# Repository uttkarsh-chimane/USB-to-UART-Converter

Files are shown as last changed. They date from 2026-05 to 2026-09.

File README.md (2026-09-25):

<h1 align="center">💡 USB Type-C to UART Converter</h1>

<p align="center">
  
  
  
  
  
</p>

---

## ⚙️ What I Built

A compact, production-style USB-to-UART bridge designed in KiCad using the CP2102N USB-to-serial interface IC.

The board enables reliable serial communication between a host PC and embedded systems for debugging, firmware flashing, and data exchange. It is designed as a plug-and-play development tool that replaces generic USB-to-UART adapters with a cleaner, integrated hardware solution.

--- 

## 🚀 Overview

This project implements a robust USB-to-UART hardware interface using a USB Type-C connector and the CP2102N USB bridge IC.

---

## 📷 Project Gallery

🧩 **3D PCB Render**

Final assembled board visualization from KiCad 3D viewer.

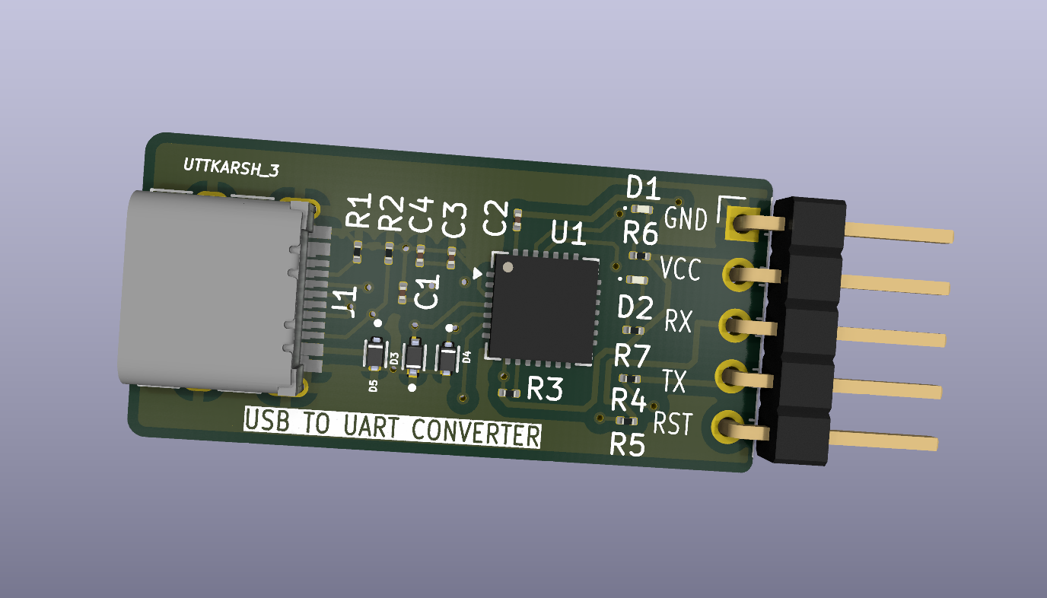
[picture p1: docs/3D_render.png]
3D PCB


🟠 **PCB Layout – Top Copper**

Top layer routing showing USB interface, CP2102N placement, and signal routing.

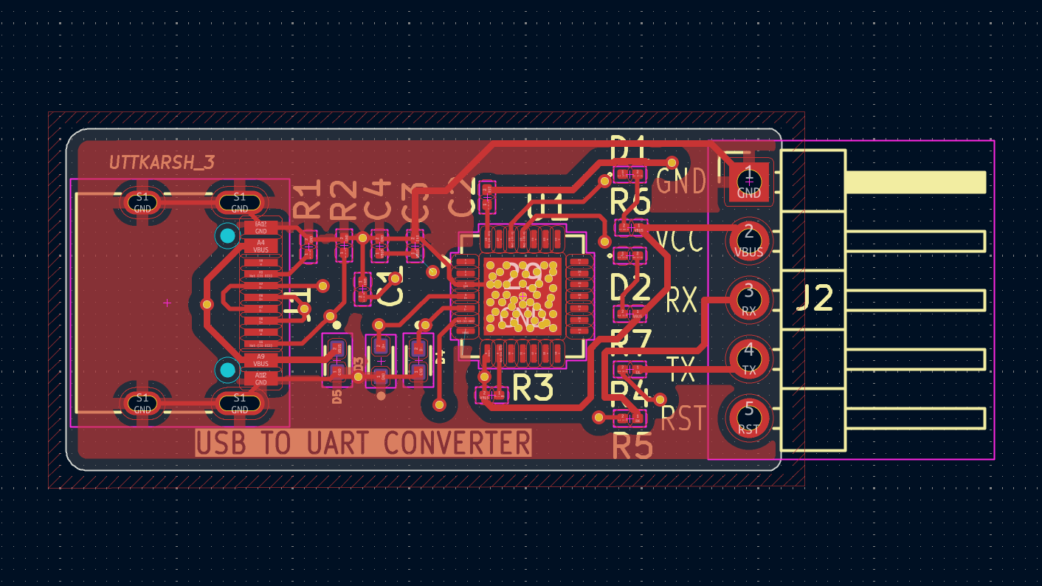
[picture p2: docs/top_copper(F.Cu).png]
Top Copper


🔵 **PCB Layout – Bottom Copper**

Bottom layer used for ground plane and signal return integrity.

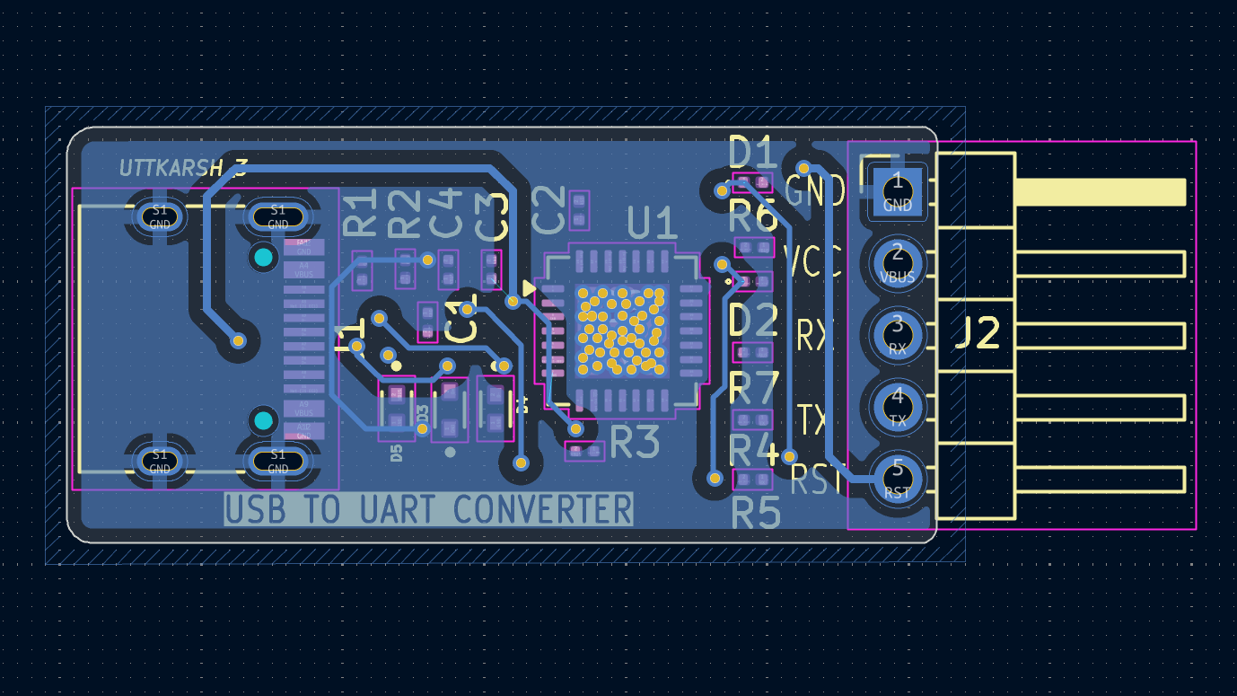
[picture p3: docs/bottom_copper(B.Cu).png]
Bottom Copper


⚙️ **Schematic – Power Section**

Power input stage including USB VBUS handling, decoupling, and regulation strategy.

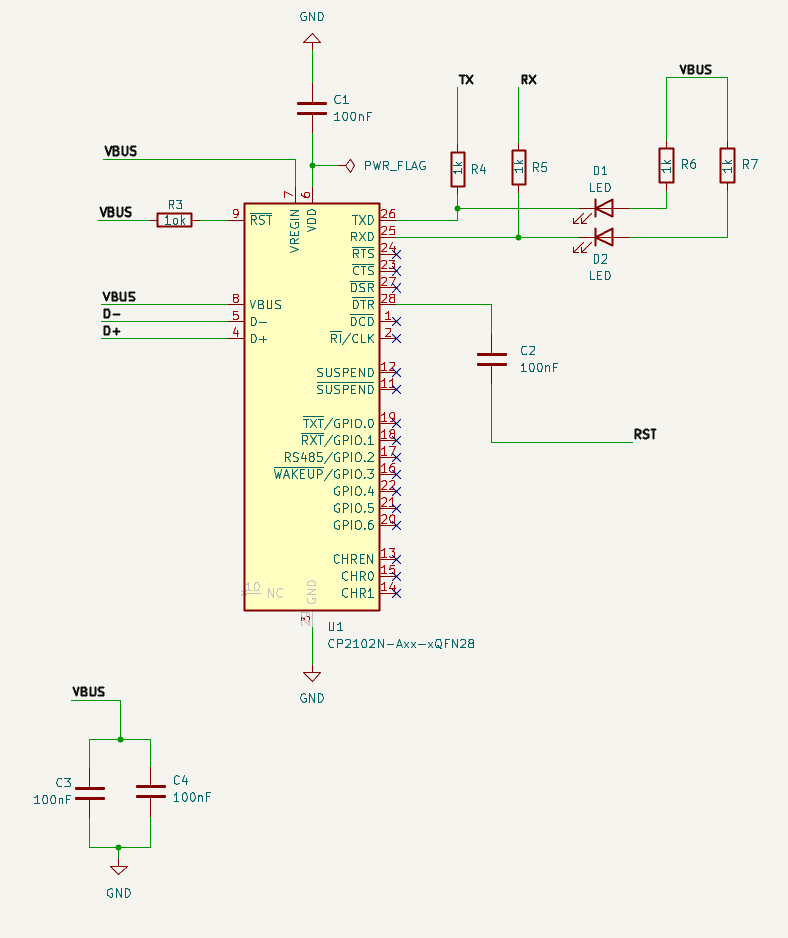
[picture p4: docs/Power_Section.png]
Power Schematic


🔌 **Schematic – USB Interface Section**

USB Type-C interface with CC resistors, ESD protection, and data routing.

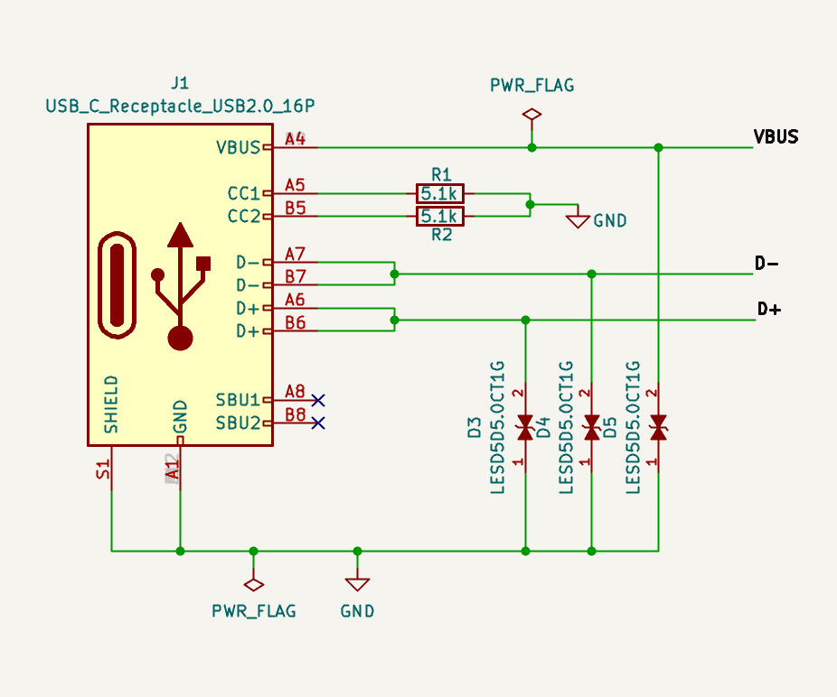
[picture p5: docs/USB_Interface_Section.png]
USB Schematic


📡 **Schematic – UART Interface Section**

CP2102N UART communication block with TX/RX routing and headers.

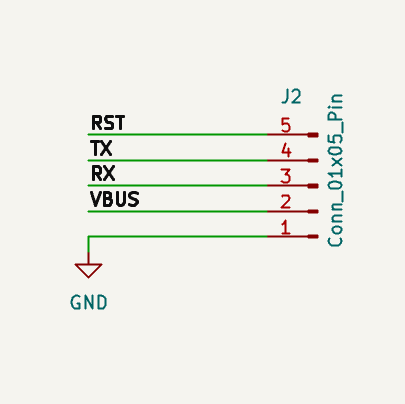
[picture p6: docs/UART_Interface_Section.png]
UART Schematic


---

## ✨ Features

* USB Type-C interface (USB 2.0)
* CP2102N USB-to-UART bridge IC
* TX/RX UART communication support
* RX/TX status indicator LEDs
* USB data line ESD protection
* Compact 2-layer PCB design
* Dedicated UART breakout header
* USB-powered operation (5V VBUS input)

---

## ⚒️ Hardware Architecture

```
USB Type-C
     │
     ▼
ESD Protection
     │
     ▼
CP2102N USB-to-UART Bridge
     │
     ▼
UART Header (TX, RX, GND, VBUS, RST)

```

---

## 🧠 Schematic Highlights

**USB Type-C Interface**

* USB 2.0 Type-C receptacle used
* CC1 and CC2 configured with 5.1kΩ pull-down resistors
* D+ and D− routed directly to CP2102N
* ESD protection added to improve robustness against hot-plug events and electrostatic discharge

**CP2102N Interface**

* Handles USB enumeration and serial conversion
* Powered directly from USB VBUS (5V)
* Decoupling capacitors placed close to power pins for stability
* Designed for stable and noise-resistant communication

**UART Header**

The board exposes a standard UART interface for external devices:

| Pin  | Function |
| ---- | --- |
| GND  | Ground |
| VBUS | 5V Supply |
| RX | UART Receive  |
| TX | UART Transmit |
| RST  | Reset Line |

---

## 🧩 PCB Design Insights

**Layout Strategy**

* Compact footprint optimized for embedded use
* USB connector placed at PCB edge for accessibility
* Solid ground plane for improved signal integrity
* Clear separation between power and signal routing

**Routing Strategy**

* USB D+ / D− routed as a differential pair
* Short and direct trace routing for signal integrity
* Decoupling capacitors placed close to IC power pins
* Continuous ground reference used to minimize noise

---

## 🧪 Applications

* MCU flashing (ESP32, STM32, AVR, etc.)
* Embedded system debugging
* Serial terminal communication
* IoT development workflows
* Firmware logging and monitoring

---

## ⚠️ Limitations

* No galvanic isolation (direct USB ground connection)
* Fixed logic levels (no onboard level shifting)
* USB-powered only (no external power input)
* No auto-reset circuitry for ESP-class boards

---

## 🚀 Future Improvements

* Auto-reset support for ESP-based boards
* Switchable 3.3V / 5V logic levels
* Onboard LDO regulator for cleaner power rail
* Polyfuse protection for overcurrent safety
* Test pads for signal debugging
* Enhanced EMI/ESD protection stage

---

## 🎓 Learning Outcomes

This project demonstrates practical experience in:

* KiCad schematic and PCB design workflow
* USB 2.0 hardware implementation
* CP2102N integration and configuration
* High-speed signal routing fundamentals
* Power integrity and decoupling design
* Ground plane design methodology

---

## 🛠️ Design Software

* KiCad 10 (Schematic + PCB Layout + 3D Render)

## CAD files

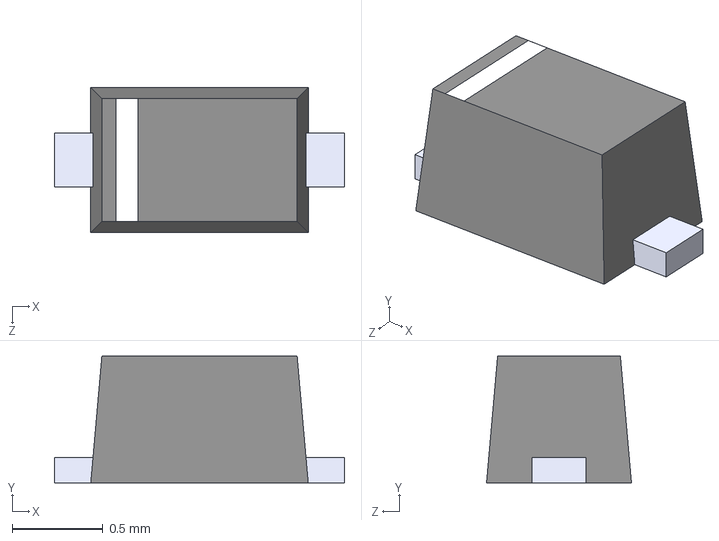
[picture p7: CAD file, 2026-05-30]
Hardware/3D_models/LESD5D5.0CT1G.step
1.60 x 0.7 x 0.8 mm

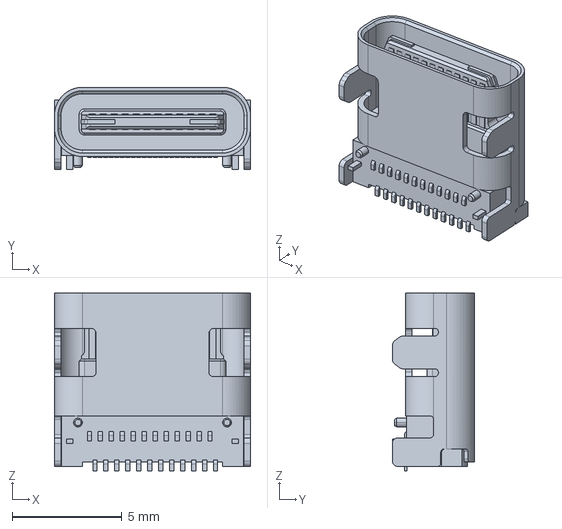
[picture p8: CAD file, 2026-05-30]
Hardware/3D_models/2345986-1--3DModel-STEP-78480.STEP
8.94 x 3.76 x 8.10 mm

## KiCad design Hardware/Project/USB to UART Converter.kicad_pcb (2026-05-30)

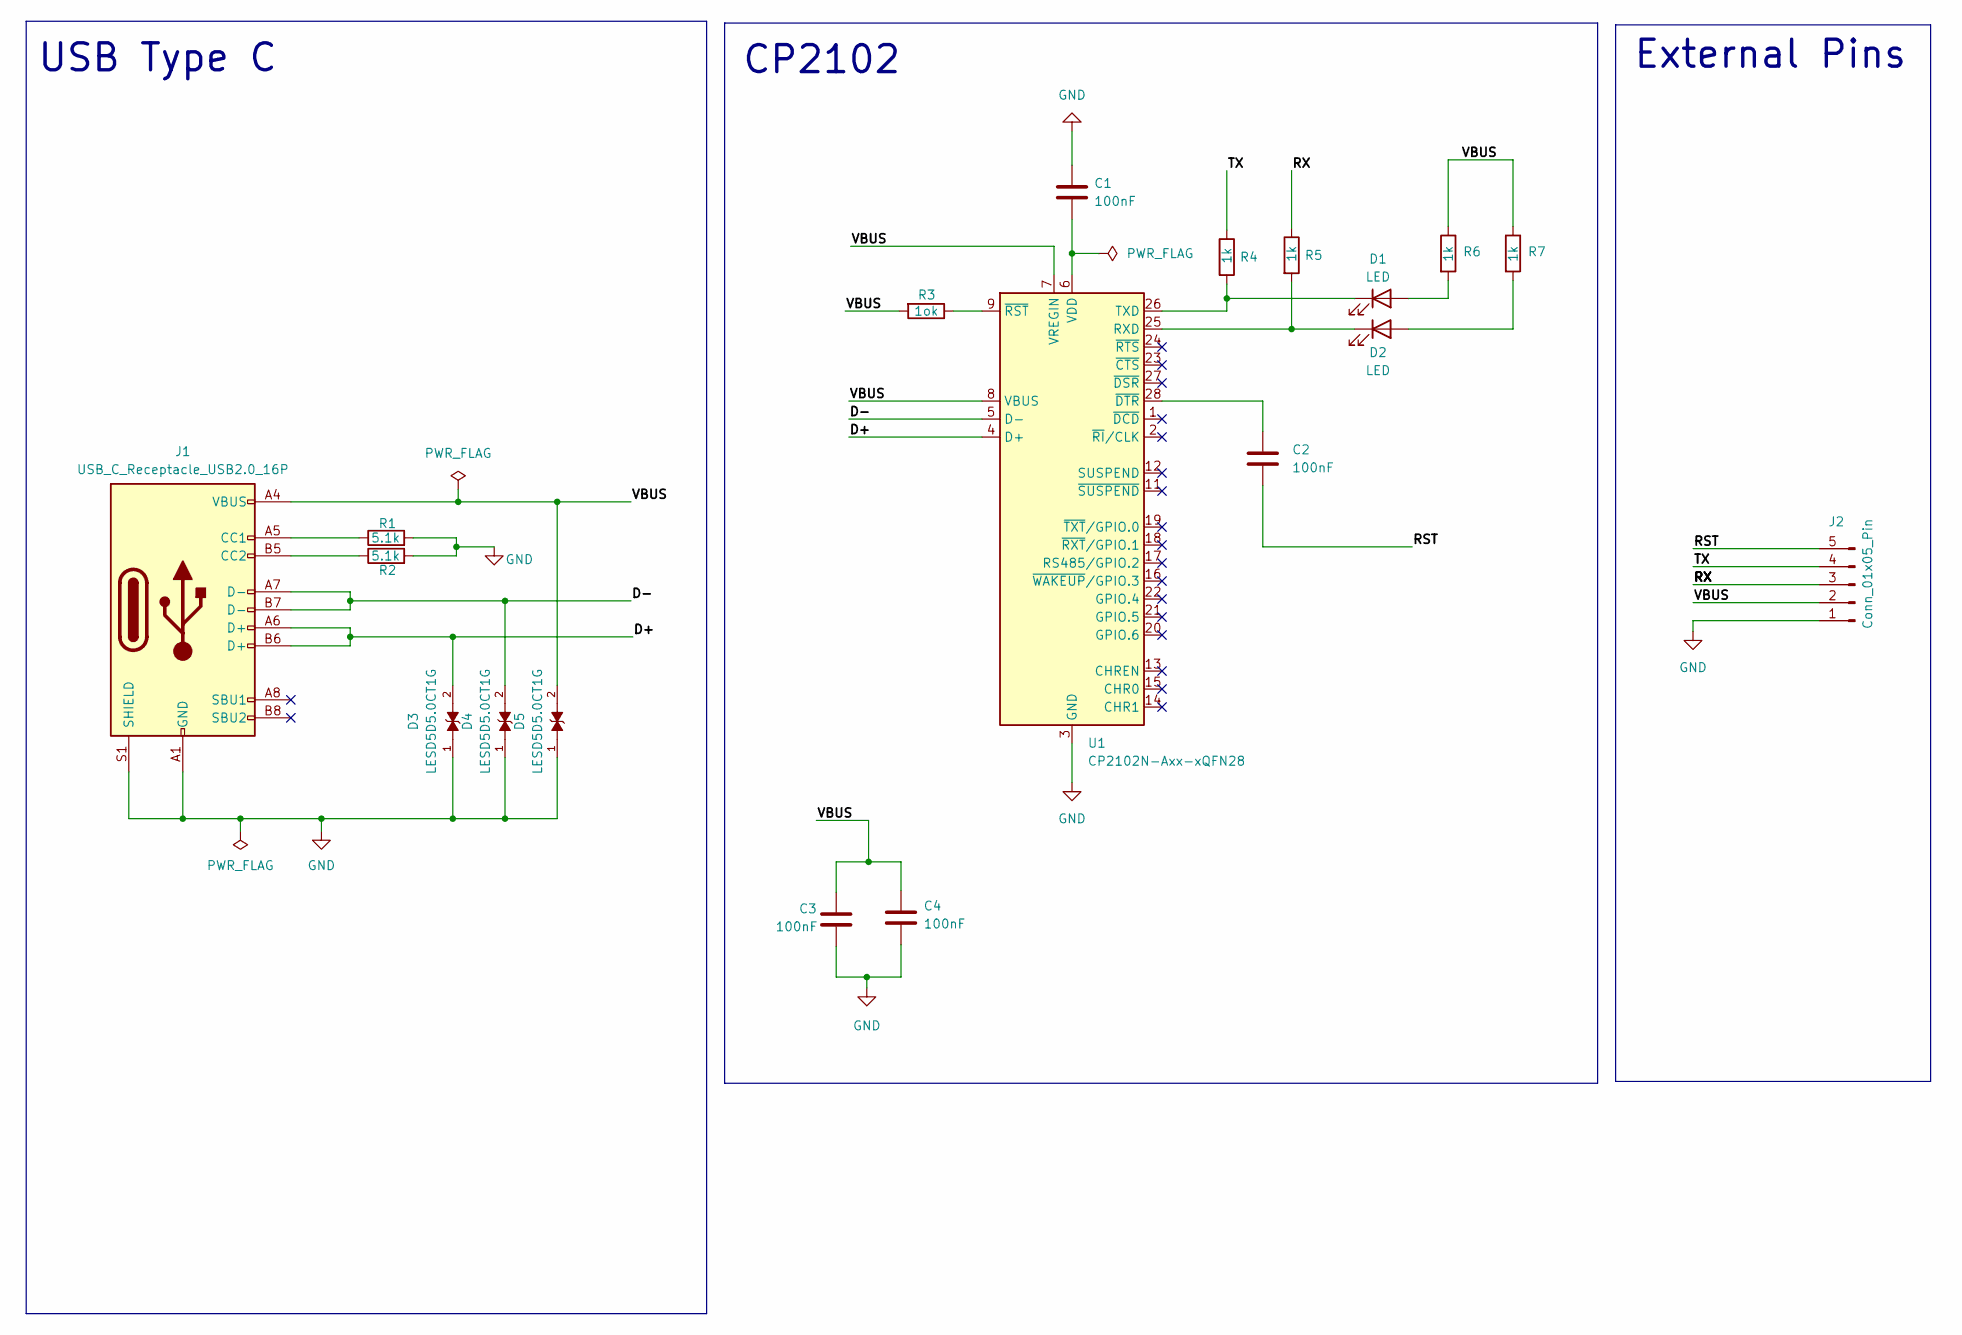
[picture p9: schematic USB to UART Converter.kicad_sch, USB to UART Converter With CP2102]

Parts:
C1, C2, C3, C4: 100nF; C_0201_0603Metric
D1, D2: LED; LED_0201_0603Metric
D3, D4, D5: LESD5D5.0CT1G; TVS_LESD5D5.0CT1G; PARTREV O
J1: USB_C_Receptacle_USB2.0_16P; USB_C_Receptacle_HRO_TYPE-C-31-M-12
J2: Conn_01x05_Pin; PinHeader_1x05_P2.54mm_Horizontal
R1, R2: 5.1k; R_0201_0603Metric
R3: 1ok; R_0201_0603Metric
R4, R5, R6, R7: 1k; R_0201_0603Metric
U1: CP2102N-Axx-xQFN28; QFN-28-1EP_5x5mm_P0.5mm_EP3.35x3.35mm

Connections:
/D+: D3.2, J1.A6 (D+), J1.B6 (D+), U1.4 (D+)
/D-: D4.2, J1.A7 (D-), J1.B7 (D-), U1.5 (D-)
/RST: C2.2, J2.5
/RX: J2.3, R5.1
/TX: J2.4, R4.1
/VBUS: C3.1, C4.1, D5.2, J1.A4 (VBUS), J1.A9 (VBUS), J1.B4 (VBUS), J1.B9 (VBUS), J2.2, R3.2, R6.1, R7.1, U1.7 (VREGIN), U1.8 (VBUS)
GND: C1.1, C3.2, C4.2, D3.1, D4.1, D5.1, J1.A1 (GND), J1.A12 (GND), J1.B1 (GND), J1.B12 (GND), J1.S1 (SHIELD), J2.1, R1.2, R2.2, U1.3 (GND), U1.29 (GND)
unnamed: D1.2 (A), R6.2
unnamed: D1.1 (K), R4.2, U1.26 (TXD)
unnamed: D2.2 (A), R7.2
unnamed: D2.1 (K), R5.2, U1.25 (RXD)
unnamed: J1.A5 (CC1), R1.1
unnamed: J1.B5 (CC2), R2.1
unnamed: C1.2, U1.6 (VDD)
unnamed: C2.1, U1.28 (~DTR)
unnamed: R3.1, U1.9 (~RST)

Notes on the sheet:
CP2102
External Pins
USB Type C

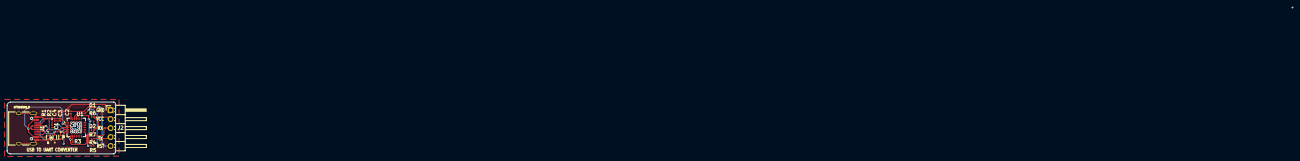
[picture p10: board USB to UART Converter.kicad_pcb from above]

Board: 2 copper layers, 30.8 x 14.7 mm, 19 parts (0 on the bottom side), 16 nets.
